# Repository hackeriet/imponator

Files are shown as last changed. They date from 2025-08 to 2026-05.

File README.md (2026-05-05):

# Hackeriet Imponator / Badge
Below, you see the layout for the test version, ordered from JLCPCB:
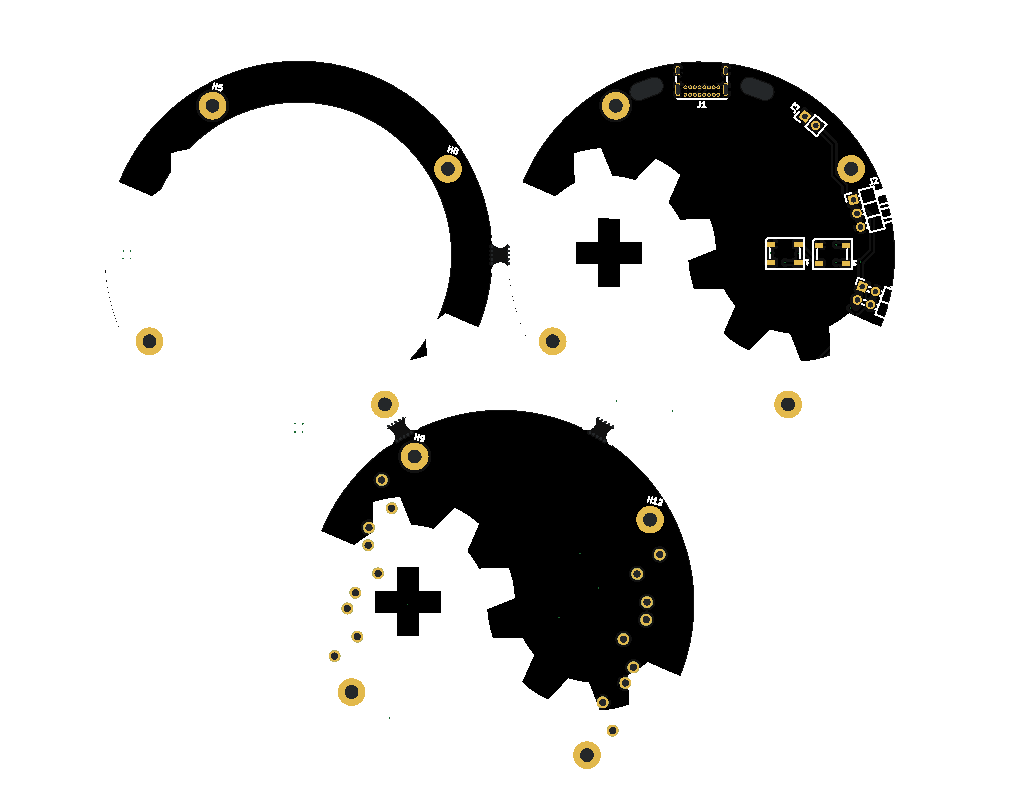
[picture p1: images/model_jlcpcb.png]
PCB Layout 3D model


## Distrubutors
When I made these, parts were bought from Digikey or Aliexpress. The PCBs were ordered from JLCPCB. 

## Read the Documentation
The MCU, sensor and USB to UART chip all have datasheets. I recommend having a look at these datasheets.

## Design
To understand the design of this, first open the file "hackeriet_imponator_schematics.pdf". This is the schematic for the PCB. As you can see the design has 6 different sections. The following sub-sections will explain each.

### MCU 
The MCU is the brain of the badge. An MCU is pretty much the same as a CPU, but smaller. For this board, we use the ATtiny804 by Microchip. As a comparison, the Ardino uses the ATmega328P. The name ATtiny804 is put together as such: 

- ATtiny: the name of the MCU family.
- 8: The MCU has 8KB of memory.
- 0: Its the 0-vesion of the ATtiny family.
- 4: Correlates to the pin count. The ATtiny804 has 14 pins.

The MCU has a 100nF capacitor between VCC and GND. This is quite standard for MCUs and sensors, but to be sure, check the datasheet.

There is also two buttons connected to pins, which the user can choose to use as they see fit. 

The UPDI pin is used for flashing the MCU. UDPI is an AVR specific protocol. With this you need just the UPDI pins,and the PCB of course needs to be powered at the same time.

The plan is to program a bootloader on the board once, and then firmware can be pushed over USB.

### RGB LEDs
The RGB LEDs are the WS2812B-4020. They are sideways programmable RGB LEDs, which are aimed into an acryllic plate that will be mounted on top of the PCB. These have four pins. VCC and GND to power the LEDs. Then DIN which is the signal into the LED and DOUT that is the signal out. With this, you can connect multiple LEDs in series, whcih lets you control multiple LEDs with only one pin.

### USB to UART
The MCU does not have USB built-in. Therefore we add a USB to UART converter chip to allow for logging and a bootloader. We use the MCP2221A. This behaves as a bridge between the USB and the MCU, translating USB signals to UART and vice versa. The ATtiny804 only supports UART on specific pins, so the pins for this was decided based on the ATtiny804 datasheet. 
The 5.1k resistors on the CC lines of the USB-C tells the charger/PC connected to the badge that it should deliver 5V over the USB. The 10k resistor on the resistor line is a Pull-Up resistor, as the reset line is active low. 10k is normal for Pull-up resistors. Other passive components come from the datasheet of the MCP2221A.

### Sensor (optional)
The sensor is the MPU-6050. This is an 3-axis gyroscope, 3-axis accelerometer and more. It is connetced to the MCU over the serial protocol I2C. The sensor is not needed for the badge to work, but makes it possible to do some cool stuff with the badge. The downside is that it requires extra parts and is harder to solder than the rest of the badge. The MPU-6050 also runs on a different voltage than the ATtiny. Therefore we use an LDO to convert the power down from 5V to 3.3V. Also, we use transistors as a logic level converter for the I2C bus.

### Power
The badge is powered by either via the USB port or by the battery connector. Tha battery connector is intended for connecting a battery to it. SW1 is used to toggle between battery in via the USB port or via the battery connector. This is to avoid issues if someone connect the battery and the USB at the same time. This means that the switch has to be soldered on for the badge to function correctly.  
Note: Switches are notorious for breaking. In which case it is possible to power the badge via the Shitty Add-on port as a hack.

### Connector
The badge has one external connector, which complies to the Shitty Add-On version one.

## TODO
We will have a soldering course soon. Here is a list of what needs to be prepared

- [ ] Get 30x diffusers, both MINUS end BODY
    - [ ] Decide diffuser adhesive design
    - [ ] Purchase acryllic
- [ ] Count parts we have, and order outstanding
    - [x] USBs
    - [x] Attinys
    - [x] MCP (USB-UART)
    - [ ] Resistors
    - [ ] Capacitors
    - [x] LEDs
    - [x] Buttons
    - [x] Switches
    - [x] Accelerometer
    - [x] LDO
    - [x] Transistors
- [x] Order PCBs
- [x] Receoive PCBs
- [ ] Pre-solder LEDs
- [ ] Safety-goggles
- [ ] Fans with carbon filters
- [ ] Write documentation
- [ ] Bring soldering irons

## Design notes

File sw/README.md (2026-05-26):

# Software Documentation
You can program the ATtiny804 however you like. I know it works with C and whatever Microchip supplies. I also suspect Rust has support for it. However, I have tested it with Arduino, and thus that is what I document below.

## Bootloader
If you want to program the badge over USB, you need a bootloader. The hex for the [Optiboot](https://github.com/Optiboot/optiboot) bootloader built for this badge is inlcuded here. The version of the hex here has the PA7 moved as to not reset the MCP2221 every time the bootloader starts.
First, write fuses, and then flash the bootloader:
```
avrdude -p t804 -c serialupdi -P /dev/ttyUSB0 -b 230400 -U fuse6:w:0x06:m -U fuse7:w:0x00:m -U fuse8:w:0x02:m
avrdude -p t804 -c serialupdi -P /dev/ttyUSB0 -b 230400 -U flash:w:bootloader_hex/optiboot_attiny804.hex:i
```

## Arduino
To program an ATtiny804 with Arduino, I used the https://github.com/SpenceKonde/megaTinyCore library. This also allows you to install the Optiboot bootloader, which allows for programing over the USB port.  
Beware, the PA7 is default for Optiboot LED. PA7 on the badge is connected to the MCP2221 UART<->USB bridge, so we have to change the default Optiboot configuration.

The megaTinyCore library also has a NeoPixel example, making it straight-forward to get started with the RGB LEDs on the badge.

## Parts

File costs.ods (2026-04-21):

Amount of total pieces | 30
Part | PCS per PCB | PCS | Price per (NOK) | Price total (NOK) | Source | Source partcode
PCB main batch | 1 | 30 | 5.4 | 162 | JLCPCB
Acrylic main batch | 1 | 30 | 12.1 | 363 | TBD
2480 battery holder | 1 | 30 | 14 | 420 | Aliexpress
WS2812B-4020 | 8 | 240 | 0.77 | 184.8
5.1K, 0603 | 2 | 60 | 0.0558 | 3.348 | DigiKey
10k, 0603 | 1 | 30 | 0.0516 | 1.548 | DigiKey
4.7K, 0603 | 2 | 60 | 0.2012 | 12.072 | DigiKey
1uF, 0603 | 1 | 30 | 0.0398 | 1.194 | DigiKey
100nF, 0603 | 1 | 30 | 0.9273 | 27.819 | DigiKey
22uF, 0603 | 1 | 30 | 0.229 | 6.87 | DigiKey
ATtiny804-SS | 1 | 30 | 8.375 | 251.25 | DigiKey | ATTINY804-SSNRCT-ND
MCP2221AxSL | 1 | 30 | 25.625 | 768.75 | DigiKey | MCP2221A-I/SL-ND
USB4085-GF-A | 1 | 30 | 8.5 | 255 | DigiKey | 2073-USB4085-GF-ACT-ND
SHIPPING |  |  |  | 0
PCB shipping |  | 1 | 44 | 44
Acrylic shipping |  | 1 | 0 | 0
TOTAL
Total price for all (USD) |  |  |  | 2501.651
Total price per PCB (USD) |  |  | 83.3883666666667
 |  | 161

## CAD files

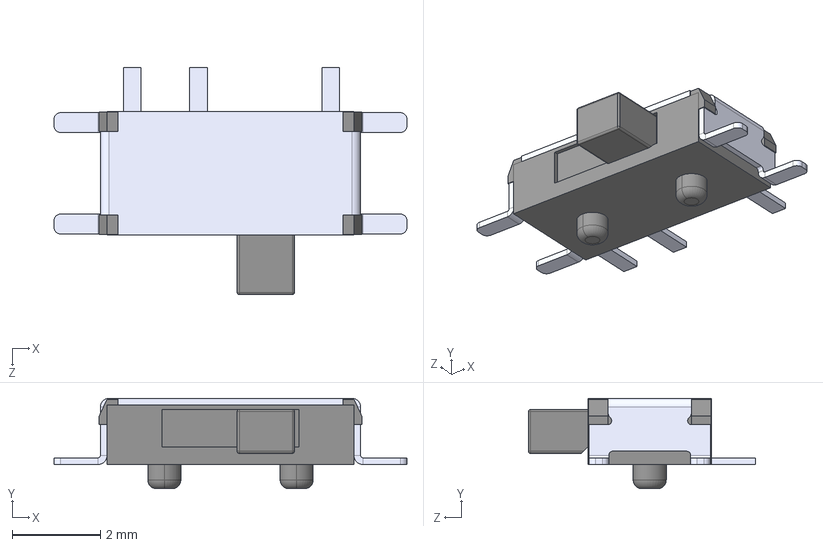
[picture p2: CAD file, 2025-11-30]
hw/schematic_footprint_external/MSK12C02--3DModel-STEP-269445.STEP
8.00 x 2.05 x 5.15 mm

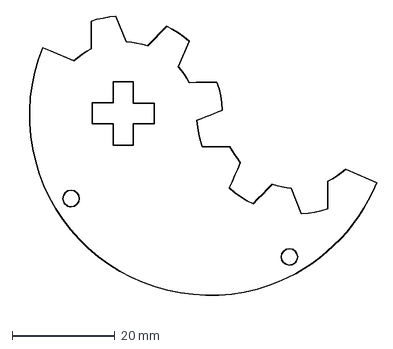
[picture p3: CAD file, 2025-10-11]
parts/hackeriet_edited.dxf
70.3 x 57.0 mm

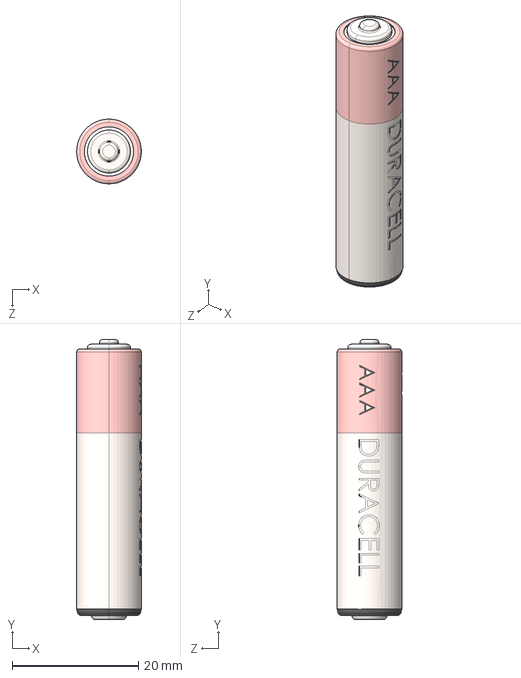
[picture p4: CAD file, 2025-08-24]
hw/schematic_footprint_external/AAA Battery.STEP
10.2 x 44.4 x 10.2 mm

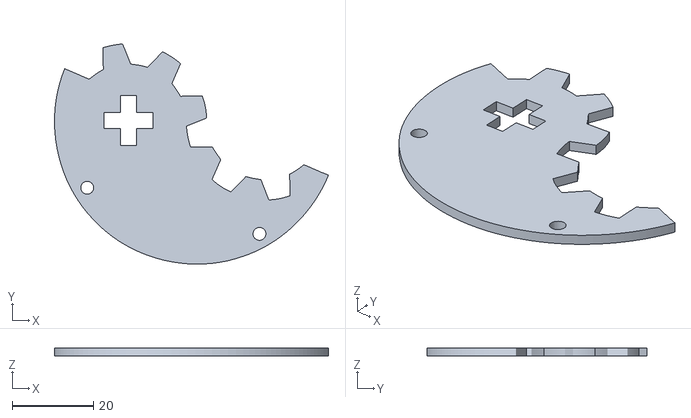
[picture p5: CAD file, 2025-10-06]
parts/hackeriet_extrude.stl
67.6 x 54.4 x 2.00

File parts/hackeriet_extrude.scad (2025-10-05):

svg_file = "hackeriet_edited.svg";
linear_extrude(height=2)
    import(svg_file);

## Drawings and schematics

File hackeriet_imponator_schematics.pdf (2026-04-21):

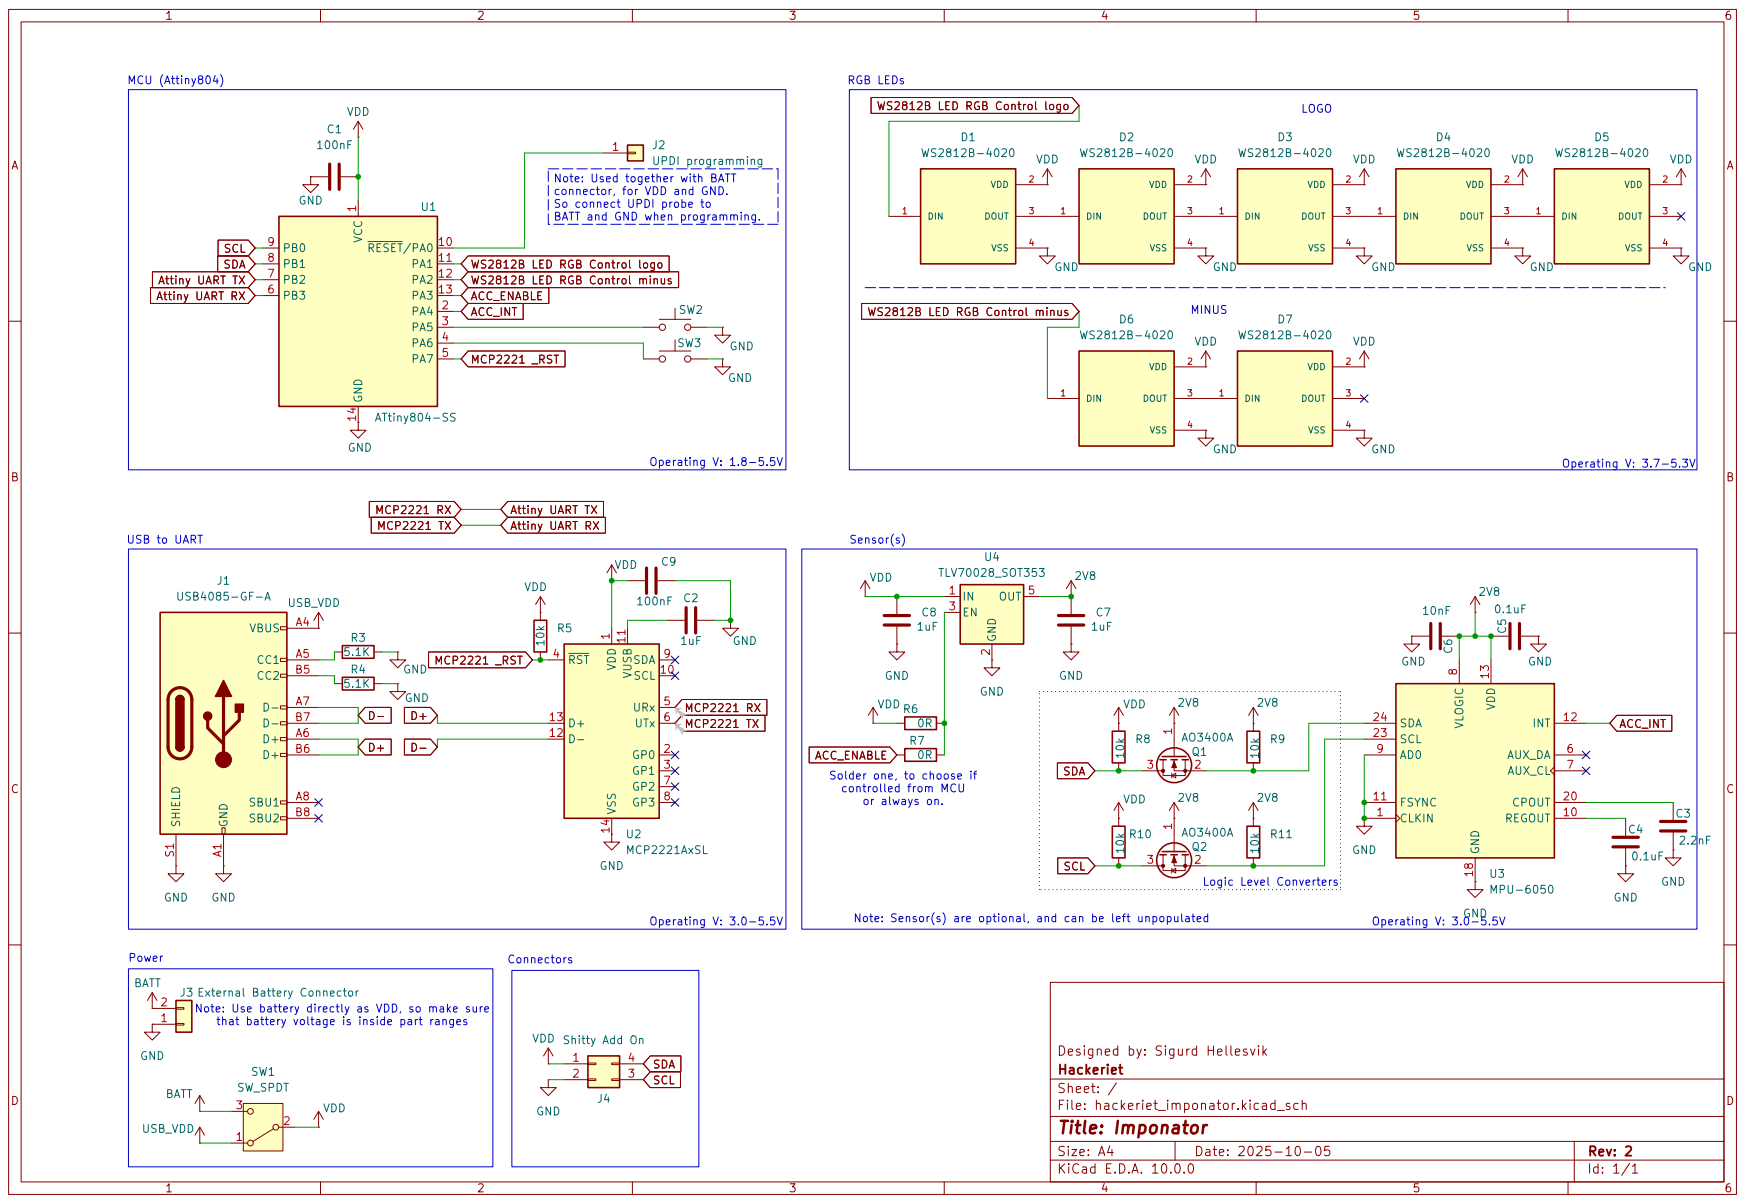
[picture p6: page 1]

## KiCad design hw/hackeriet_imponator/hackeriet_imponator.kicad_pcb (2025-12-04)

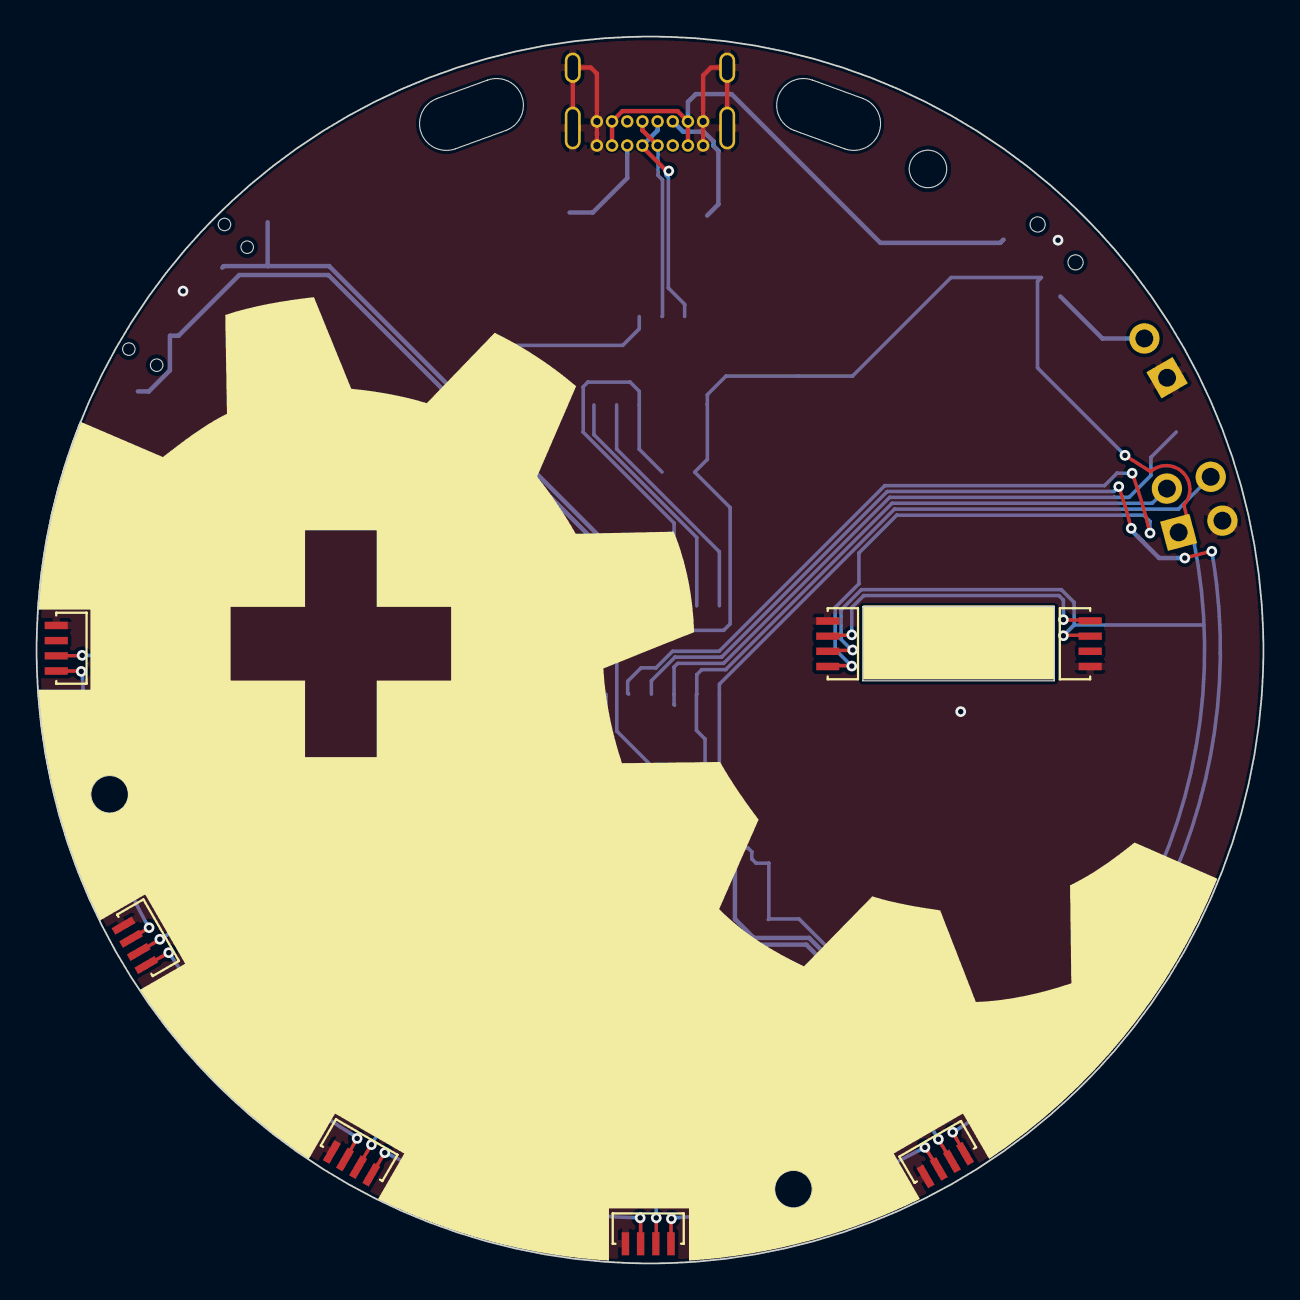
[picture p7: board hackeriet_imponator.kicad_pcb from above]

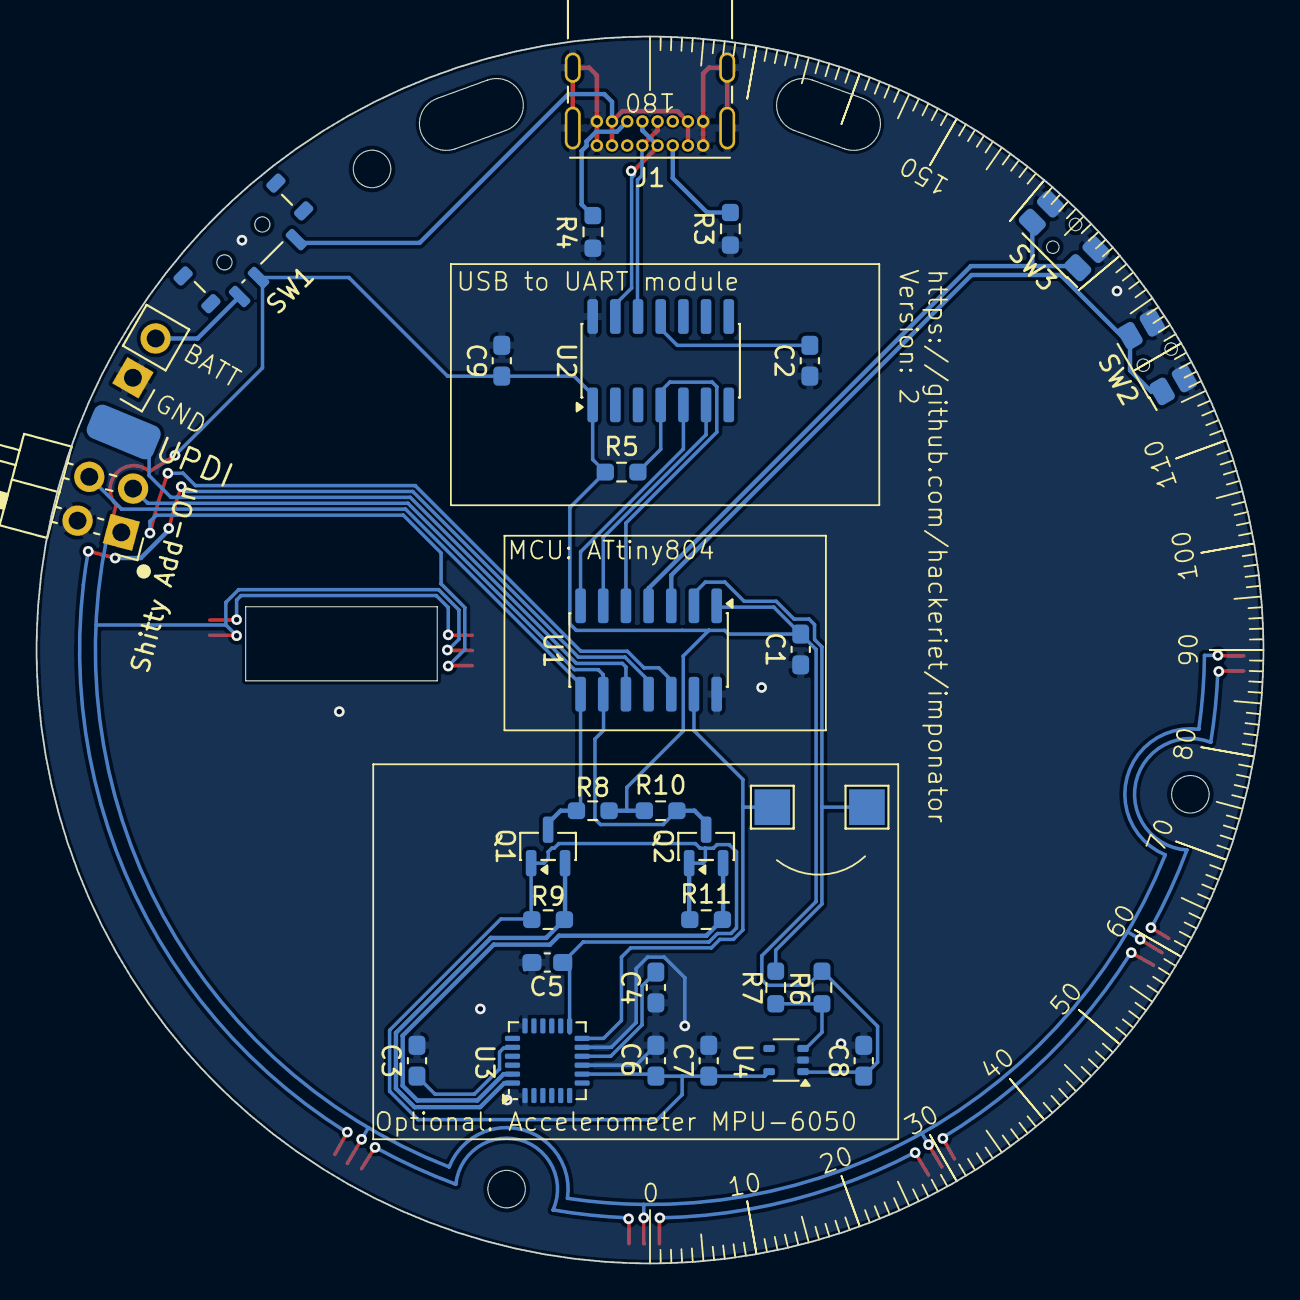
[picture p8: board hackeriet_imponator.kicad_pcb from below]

Board: 2 copper layers, 68.7 x 68.7 mm, 38 parts (31 on the bottom side), 32 nets.

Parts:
C1, C9: 100nF; C_0603_1608Metric_Pad1.08x0.95mm_HandSolder
C2, C7, C8: 1uF; C_0603_1608Metric_Pad1.08x0.95mm_HandSolder
C3: 2.2nF; C_0603_1608Metric_Pad1.08x0.95mm_HandSolder
C4, C5: 0.1uF; C_0603_1608Metric_Pad1.08x0.95mm_HandSolder
C6: 10nF; C_0603_1608Metric_Pad1.08x0.95mm_HandSolder
D1, D2, D3, D4, D5, D6, D7: WS2812B-4020; LED_WS2812B-4020
J1: USB4085-GF-A; USB_C_Receptacle_GCT_USB4085
J2: UPDI programming; SolderWirePad_1x01_SMD_2x4mm
J3: External Battery Connector; PinHeader_1x02_P2.54mm_Vertical
J4: Shitty Add-On; PinHeader_2x02_P2.54mm_Horizontal
Q1, Q2: AO3400A; SOT-23
R3, R4: 5.1K; R_0603_1608Metric_Pad0.98x0.95mm_HandSolder
R5, R8, R9, R10, R11: 10k; R_0603_1608Metric_Pad0.98x0.95mm_HandSolder
R6, R7: 0R; R_0603_1608Metric_Pad0.98x0.95mm_HandSolder
SW1: SW_SPDT; SW_SPDT_Shouhan_MSK12C02
SW2, SW3: User configurable; SW_SPST_EVQP7C
U1: ATtiny804-SS; SOIC-14_3.9x8.7mm_P1.27mm
U2: MCP2221AxSL; SOIC-14_3.9x8.7mm_P1.27mm
U3: MPU-6050; InvenSense_QFN-24_4x4mm_P0.5mm
U4: TLV70028_SOT353; SOT-353_SC-70-5

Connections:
2V8: C5.2, C6.2, C7.1, Q1.1 (G), Q2.1 (G), R9.1, R11.1, U3.8 (VLOGIC), U3.13 (VDD), U4.5 (OUT)
ACC_ENABLE: R7.1, U1.2 (PA4)
ACC_INT: U1.13 (PA3), U3.12 (INT)
Attiny UART RX: U1.6 (PB3), U2.6 (UTx)
Attiny UART TX: U1.7 (PB2), U2.5 (URx)
BATT: J3.2, SW1.3 (C)
D+: J1.A6 (D+), J1.B6 (D+), U2.13 (D+)
D-: J1.A7 (D-), J1.B7 (D-), U2.12 (D-)
GND: C1.1, C2.2, C3.1, C4.1, C5.1, C6.1, C7.2, C8.2, C9.2, D1.4 (VSS), D2.4 (VSS), D3.4 (VSS), D4.4 (VSS), D5.4 (VSS), D6.4 (VSS), D7.4 (VSS), J1.A1 (GND), J1.A12 (GND), J1.B1 (GND), J1.B12 (GND), J1.S1 (SHIELD), J3.1, J4.2, R3.2, R4.2, SW2.2, SW3.2, U1.14 (GND), U2.14 (VSS), U3.1 (CLKIN), U3.9 (AD0), U3.11 (FSYNC), U3.18 (GND), U4.2 (GND)
MCP2221 _RST: R5.2, U1.5 (PA7), U2.4 (~RST)
unnamed: D1.3 (DOUT), D2.1 (DIN)
unnamed: D2.3 (DOUT), D3.1 (DIN)
unnamed: D3.3 (DOUT), D4.1 (DIN)
unnamed: D4.3 (DOUT), D5.1 (DIN)
unnamed: D6.3 (DOUT), D7.1 (DIN)
unnamed: J1.A5 (CC1), R3.1
unnamed: J1.B5 (CC2), R4.1
unnamed: J2.1, U1.10 (~RESET/PA0)
unnamed: Q1.2 (S), R9.2, U3.24 (SDA)
unnamed: Q2.2 (S), R11.2, U3.23 (SCL)
unnamed: SW2.1, U1.3 (PA5)
unnamed: SW3.1, U1.4 (PA6)
unnamed: C2.1, U2.11 (VUSB)
unnamed: C3.2, U3.20 (CPOUT)
unnamed: C4.2, U3.10 (REGOUT)
unnamed: R6.2, R7.2, U4.3 (EN)
SCL: J4.3, Q2.3 (D), R10.2, U1.9 (PB0)
SDA: J4.4, Q1.3 (D), R8.2, U1.8 (PB1)
USB_VDD: J1.A4 (VBUS), J1.A9 (VBUS), J1.B4 (VBUS), J1.B9 (VBUS), SW1.1 (A)
VDD: C1.2, C8.1, C9.1, D1.2 (VDD), D2.2 (VDD), D3.2 (VDD), D4.2 (VDD), D5.2 (VDD), D6.2 (VDD), D7.2 (VDD), J4.1, R5.1, R6.1, R8.1, R10.1, SW1.2 (B), U1.1 (VCC), U2.1 (VDD), U4.1 (IN)
WS2812B LED RGB Control logo: D1.1 (DIN), U1.11 (PA1)
WS2812B LED RGB Control minus: D6.1 (DIN), U1.12 (PA2)

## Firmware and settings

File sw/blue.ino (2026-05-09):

// This was vibecoded. Do not trust it.
#include <tinyNeoPixel.h>

#define PIN PIN_PA1
#define PIN_2 PIN_PA2
#define NUM_LEDS 5
#define NUM_LEDS_2 2
#define BRIGHTNESS 25

#define USE_RGBW 0

#if USE_RGBW
#define PIXEL_TYPE (NEO_GRBW + NEO_KHZ800)
#else
#define PIXEL_TYPE (NEO_GRB + NEO_KHZ800)
#endif

tinyNeoPixel strip(NUM_LEDS, PIN, PIXEL_TYPE);
tinyNeoPixel strip2(NUM_LEDS_2, PIN_2, PIXEL_TYPE);

void setup() {
  strip.begin();
  strip.setBrightness(BRIGHTNESS);
  strip.show();

  strip2.begin();
  strip2.setBrightness(BRIGHTNESS);
  strip2.show();
}

void loop() {
  // Set all LEDs on strip 1 to blue
  for (uint8_t i = 0; i < NUM_LEDS; i++) {
#if USE_RGBW
    strip.setPixelColor(i, 0, 0, 255, 0);
#else
    strip.setPixelColor(i, 0, 0, 255);
#endif
  }
  strip.show();

  // Set all LEDs on strip 2 to blue
  for (uint8_t i = 0; i < NUM_LEDS_2; i++) {
#if USE_RGBW
    strip2.setPixelColor(i, 0, 0, 255, 0);
#else
    strip2.setPixelColor(i, 0, 0, 255);
#endif
  }
  strip2.show();

  delay(200);
}

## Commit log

2025-08-23 Added MCU and some LEDs for main part.
    TODO: Battery holder and top ring
    [hackeriet_imponator.kicad_pcb, hackeriet_imponator.kicad_sch]
2025-08-24 Added some external components for battery holders
2025-08-24 Added ring. Added programming header. Started with batt connector
    [Outer ring.kicad_sch, hackeriet_imponator.kicad_pcb, hackeriet_imponator.kicad_sch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]
2025-08-24 Moved things around to clean up
    [Outer ring.kicad_sch, hackeriet_imponator.kicad_pcb, hackeriet_imponator.kicad_sch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]
2025-08-24 Added Batttery holders. Some general routing
    [AAA Battery.STEP, hackeriet_imponator.kicad_pcb, main_pcb.kicad_sch]
2025-08-24 Started changing out ATmega328P with ATmega32URC because the latter got built-in USB driver, making the design easier, if a bit more expensive
    [main_pcb.kicad_sch]
2025-08-24 Imported SVG of logo directly to line stuff up better. Also better silkscreen.
    [hackeriet_imponator.kicad_pcb]
2025-09-03 Added cutout
    [hackeriet_edited.dxf, hackeriet_imponator.kicad_pcb]
2025-10-05 Resized logo and made it into part
    [hackeriet_edited.dxf, hackeriet_extrude.scad, hackeriet_extrude.stl]
2025-10-05 Major change. Resized PCB. Changed CPU. Added USB. Added headers. Added another layer for batteries
    [battery_addon.kicad_sch, hackeriet_imponator.kicad_pcb, hackeriet_imponator.kicad_sch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]
2025-10-05 Added paneling with mouse bites
    [hackeriet_imponator.kicad_pcb]
2025-10-05 Added final touches. This version will be ordered
    [hackeriet_imponator.kicad_pcb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]
2025-10-05 Regenerated gerbers without silkscreen on pads. When I said 'will be ordered' last commit, I mean just a test batch.
    [hackeriet_imponator-job.gbrjob]
2025-10-06 Added holes to plate model. Also generated DXF, in case its needed for production.
    [hackeriet_edited.dxf, hackeriet_extrude.stl]
2025-10-06 Two more TODOs, on silkscreen improvements.
2025-10-11 Added spreadsheet to see costs. Waiting for some costs still
    [costs.ods]
2025-10-11 Improved DXF
    [hackeriet_edited.dxf]
2025-10-13 Removed secondary source, as it was too expensive. Added Vendor, and some vendor codes
    [costs.ods]
2025-10-21 Added todo for power source switch
2025-10-21 Added TODO for button
2025-10-23 Added schematics as PDF
2025-10-23 Added footprint as well.
2025-10-26 Add TODO for sideways LEDs
2025-11-23 Removed outer ring and battery backplate. Ready to apply TODOs
    [hackeriet_imponator.kicad_pcb, hackeriet_imponator.kicad_sch, main_pcb.kicad_sch]
2025-11-23 Added switch between batt and USB. Changed LEDs to sideways
    [hackeriet_imponator.kicad_pcb, hackeriet_imponator.kicad_sch]
2025-11-23 Edited logo to have space for sideways LEDs
2025-11-23 Fine-tuned silkscreen logo and LED spacing.
    [hackeriet_imponator.kicad_pcb, hackeriet_imponator.kicad_sch]
2025-11-24 Added accelerometer to schematic. Also crossed off some TODOs that were already done.
    [hackeriet_imponator.kicad_sch]
2025-11-29 Added LDO for accelerometer
    [hackeriet_imponator.kicad_sch]
2025-11-30 Fixed LED pinout. Added PCB button. Distributed headers along side.
    [MSK12C02--3DModel-STEP-269445.STEP, hackeriet_imponator.kicad_pcb, hackeriet_imponator.kicad_sch]
2025-11-30 Added holes to design
2025-11-30 Did a bunch of routing and changed holes. Also some silk
    [hackeriet_imponator.kicad_pcb, hackeriet_imponator.kicad_sch]
2025-11-30 More routing
    [hackeriet_imponator.kicad_pcb, hackeriet_imponator.kicad_sch]
2025-12-03 Added Logic Level Converter. Added GND vias. Routed the rest. Ran Design Rules test and fixed stuff.
    [hackeriet_imponator.kicad_pcb, hackeriet_imponator.kicad_sch]
2025-12-04 Cleaned up silkscreen. Added some more silkscreen stuff.
    [hackeriet_imponator.kicad_pcb]
2025-12-04 Some cleanup
    [Outer ring.kicad_sch, battery_addon.kicad_sch, main_pcb.kicad_sch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]
2025-12-04 Revision 2 ready for ordering
    [hackeriet_imponator.kicad_pcb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]
2026-04-14 Updated costs list. Added todo for course
    [costs.ods]
2026-04-21 Got PCBs
2026-04-21 Added acryllic cost. This seems to be the final one
    [costs.ods]
2026-04-21 Updated schematic
2026-05-09 Fixed pin number
2026-05-26 Added fuses docs
